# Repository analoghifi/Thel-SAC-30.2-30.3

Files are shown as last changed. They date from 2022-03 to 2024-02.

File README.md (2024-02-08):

# Thel SAC 30.2/30.3
Thel "**S**uper **A**ctive **C**rossover" (german: SA**W** 30.2/30.3) | 2-input ➔ 4-ouput | switchable: either 2-way-stereo or 3-way-mono | 24dB/Oct. Linkwitz-Riley  
realized as a 4th-order "state variable filter" according to:  
*>> Audio-Engineering-Society, Edition 1983 October 8-12, No. 2011 (B-2) by its inventor **Dennis A. Bohn**, Rane Corporation, Mountlake Terrace, Washington <<*  
➔ <a href="/docs/related/2099_AES_preprint_2011(B2)_1983.pdf">2099_AES_preprint_2011(B2)_1983.pdf</a>

maintaining a phase shift of 0° between the filter passes\* at any time at any frequency.  
*>>All in all, this results in perfect transmission in terms of time and level. The compromise is that the frequency-dependent phase rotation of this analogue filter is not shifted between the neighboring filter passes\*, but only between the input and output of the crossover.<<*  
  
\*(low-pass / band-pass / high-pass)   
<hr />

The original versions are equipped with balanced (symmetrical ) audio inputs  
but unbalanced (asymmetrical) audio outputs.
<hr />

In the <a href="/hardware">"hardware"</a> folder of this repository you can see the different versions of this module as they were built by THEL over the years and decades.  
This does NOT necessarily mean that the latest, newest version ("version 07.2017 until now") is also the "best" version.  
As you can see, in this case the sub-bass-boost feature and the extended supply voltage section is missing in the latest SAC 30.x  
and the very good PP 1% film/foil precision capacitors were switched to "normal" WIMA MKP 2.5% - 10% (or even MKS only).  
However, the latter in particular contradicts the goal of the 0° phase shift, because this requires that the determining filter capacitors and resistors have a tolerance of 1% or better (!).  
(In addition, the PP film/foil also sound better than the MKP types ➔ lower (and less frequency-dependent) dissipation factor "tan delta" etc...)  
On the other hand the latest, newest version ("version 07.2017 until now") introduces a much better input section (with 2 Op-Amps) in comparision to the previous model ("version 2011-2017")  
  
### So here is a comparison of this two versions and their specific pros and cons:  
#### Latest "<a href="/hardware/2)%20version%2007.2017%20until%20now">version 07.2017 until now</a>":  
:x: no "bass-boost" feature  
:x: using only "normal" capacitors in the filter section WIMA MKP 2.5% - 10% (or even worse: WIMA MKS)  
:x: no "Multi-Footprint" for the 8 filter capacitors (to optionally use different sizes and shapes of filter caps)  
:x: therefore no possibility to use the beloved tower style 1% precision KP film/foil caps in the filter section  
:x: no input caps in the power supply section  
:x: using of SOT-32 power transistors "only" in the power supply section (BD139/BD140 80V/1,5A/1,25W)  
:x: limited power supply voltage range of ±9V ... ±36V DC "only"  
:x: no possibility and space on the PCB to use optional (front panel mount) level potentiometers  
:x: no (RF-) bypass caps directly on the supply pins of the OP amps, although they are mandatory in every data sheet (for very good reasons)  
:heavy_check_mark: better audio input section with 2 OP-Amps (better symmetry / higher CMRR)   
:heavy_check_mark: using lower resistors in the filter section (less noise in theory)  
:heavy_check_mark: smaller dimensions (85 x 121mm)   
#### Previous "<a href="/hardware/3)%20version%202011-2017">version 2011-2017</a>":  
:heavy_check_mark: "bass-boost" feature  
:heavy_check_mark: using the high grade tower style 1% precision KP film/foil caps in the filter section  
:heavy_check_mark: "Multi-Footprint" for the 8 Filter capacitors to optionally use different sizes and shapes of filter caps  
:heavy_check_mark: 2 input caps (100µF) in the power supply section  
:heavy_check_mark: using of TO-220 power transistors in the power supply section (TIP132/TIP137 100V/8A/2,0W)  
:heavy_check_mark: extended power supply voltage range of ±9V ... ±60V DC  
:heavy_check_mark: preparation for using optional (front panel mount) level potentiometers directly on the PCB (in this case: TKD CP601 \[Conductive Plastic\])   
:x: no (RF-) bypass caps directly on the supply pins of the OP amps, although they are mandatory in every data sheet (for very good reasons)  
:x: using a simplified audio input section with 1 OP-Amp only (worse symmetry / lower CMRR)  
:x: using higher resistors in the filter section (more noise in theory)    
:x: larger dimensions (95 x 142mm)  
### my plans:  
* in the first step I will design a \"<a href="/hardware/1)%20my%20new%20version">new SAC30</a>\", which combines the advantages of the two versions mentioned above,  
it will still be in THT technology but 2 layer PCB, so that an average hobbyist can easily build it himself       
* the next step will be to create an all SMD version of this (eventually including 1% C0G ceramic filter caps), with some new features like symmetrical outputs, input/output ESD protection, ...)

<hr />  

## latest version as of 07.2017 until today:  
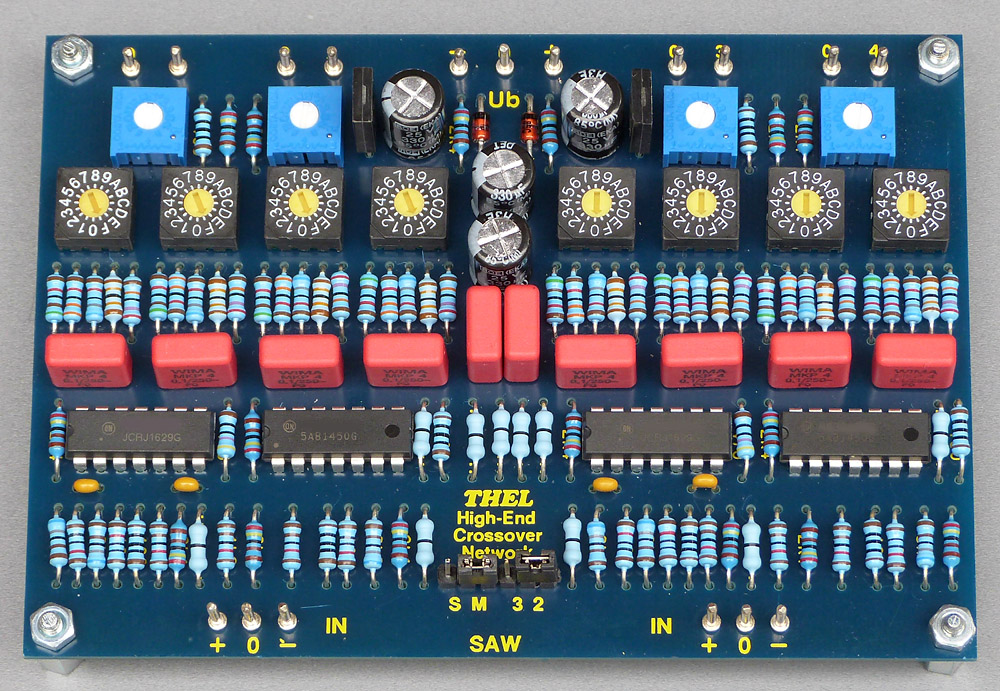
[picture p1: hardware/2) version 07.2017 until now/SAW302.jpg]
  
  
## better previous version (built 2011-2017):
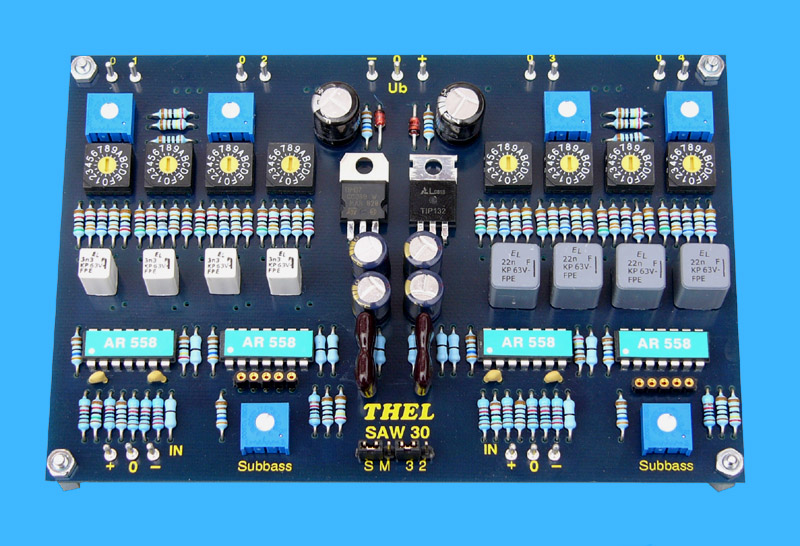
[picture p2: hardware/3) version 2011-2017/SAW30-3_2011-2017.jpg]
   
using optional (front panel mount) level potentiometers directly on the PCB (in this case: TKD CP601 [Conductive Plastic]):   
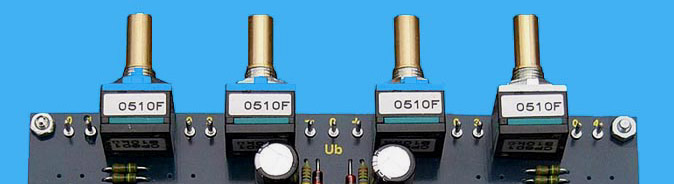
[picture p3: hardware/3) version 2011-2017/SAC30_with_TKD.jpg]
   

https://web.archive.org/web/20071014012620/http://www.thel-audioworld.de/module/saw/saw.htm  
old frequency-table: https://web.archive.org/web/20160324050324/http://thel-audioworld.de/module/saw/SAWTAB.GIF  
https://web.archive.org/web/20110927050632/http://www.thel-audioworld.de/module/saw/saw.htm  
https://web.archive.org/web/20160406211449/http://www.thel-audioworld.de/MODULE/SAW/saw.htm  
https://web.archive.org/web/20180819222254/http://www.thel-audioworld.de/module/SAW/saw.htm  

----

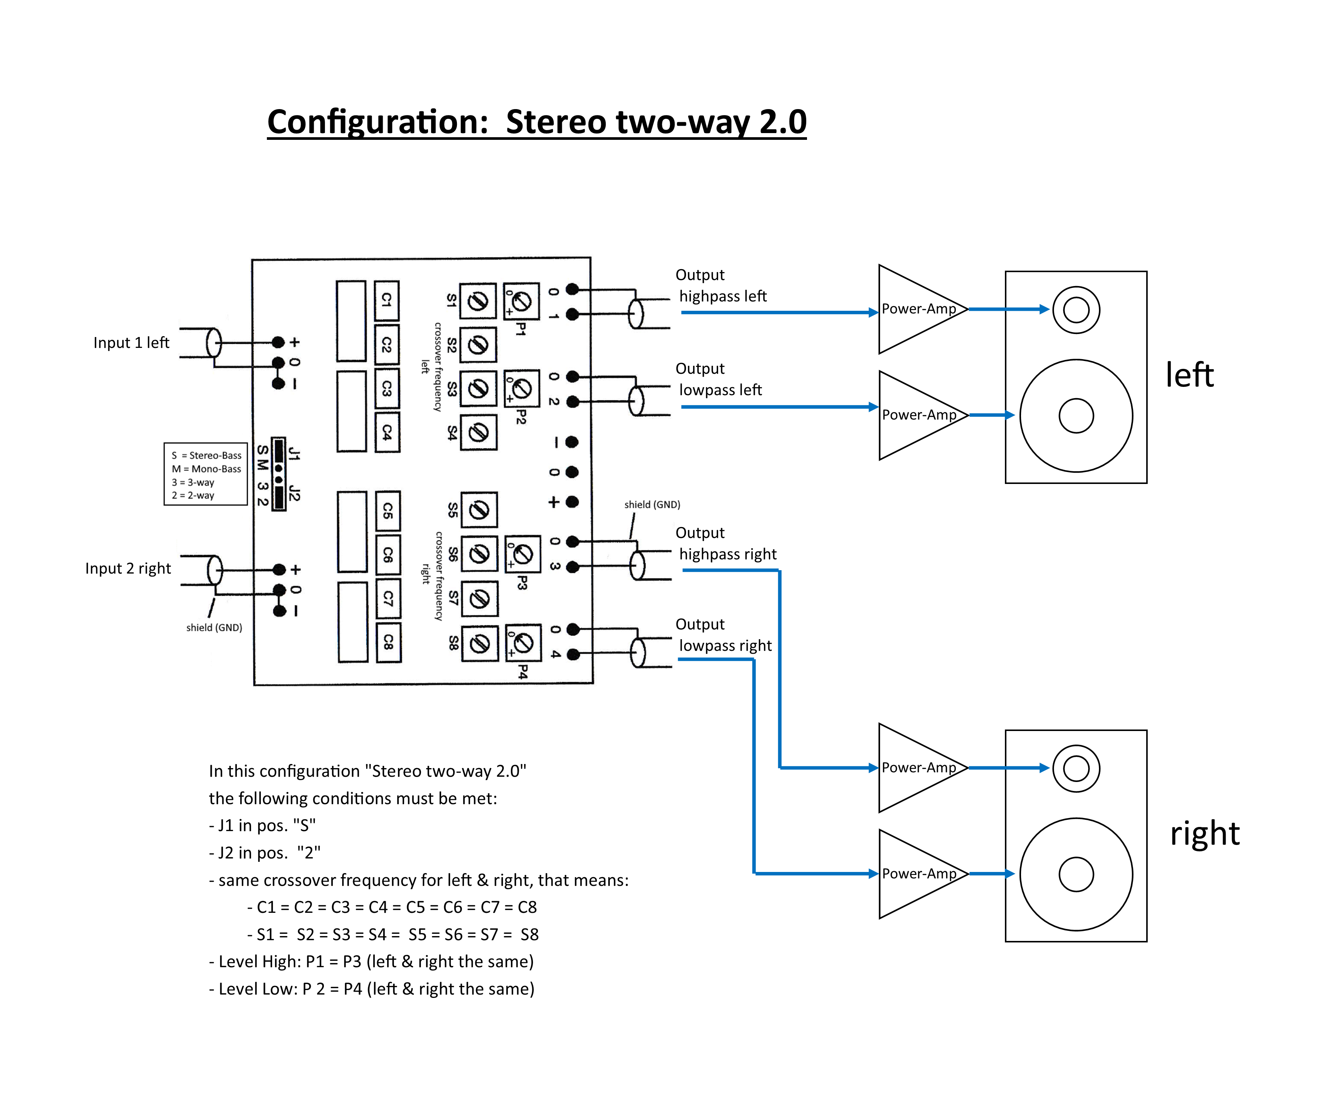
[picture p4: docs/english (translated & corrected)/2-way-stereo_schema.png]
  
  
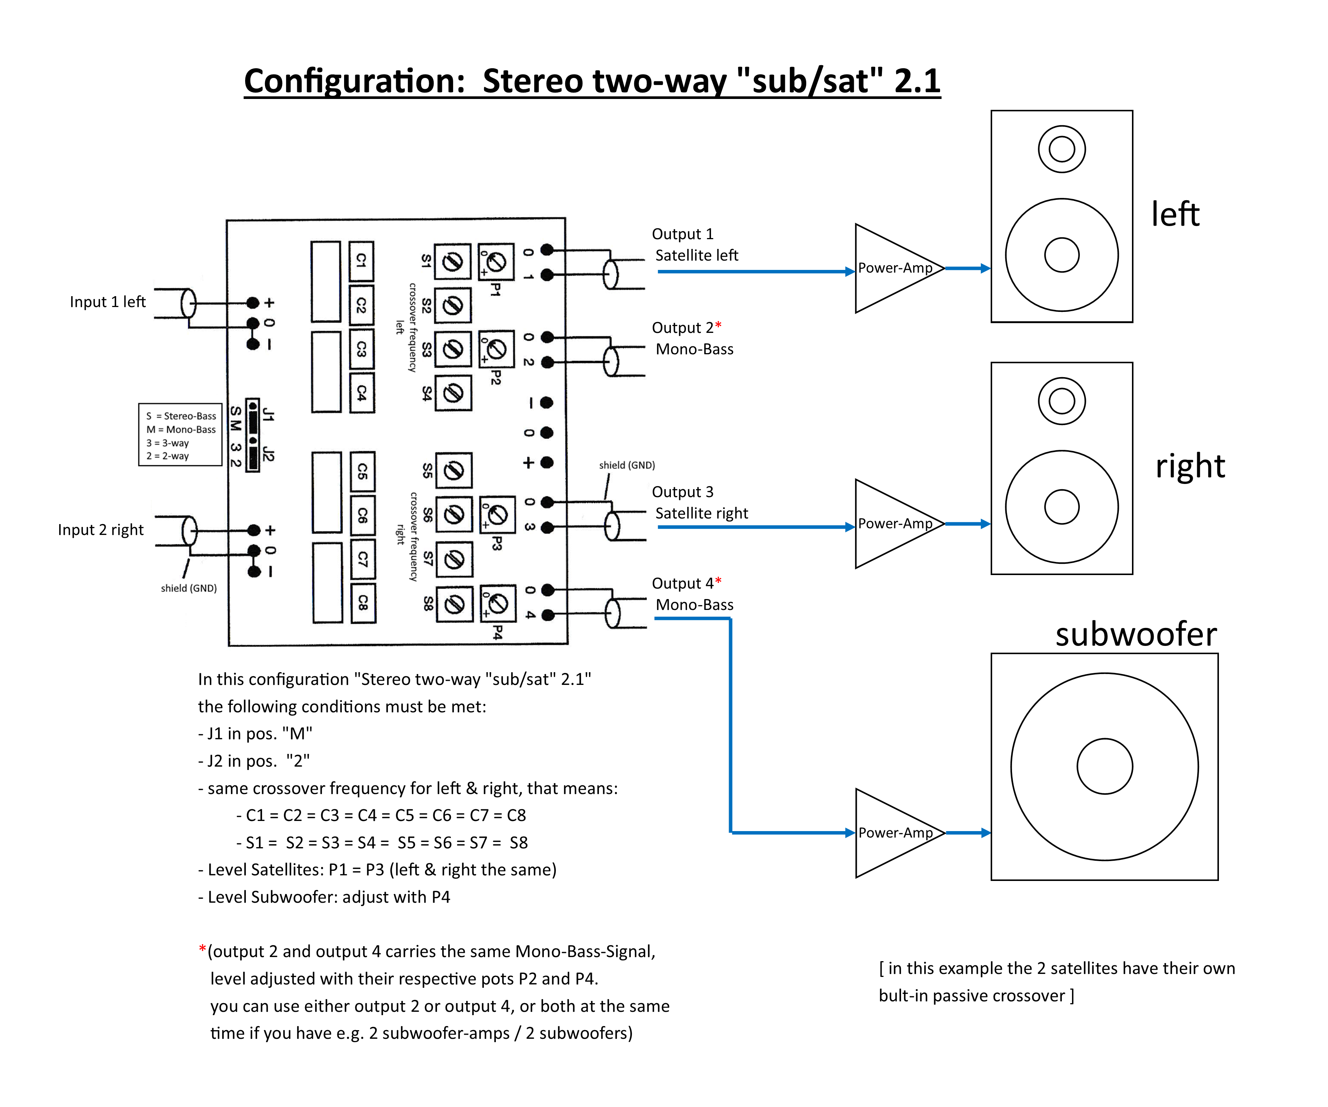
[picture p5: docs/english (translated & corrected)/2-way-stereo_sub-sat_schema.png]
  
  
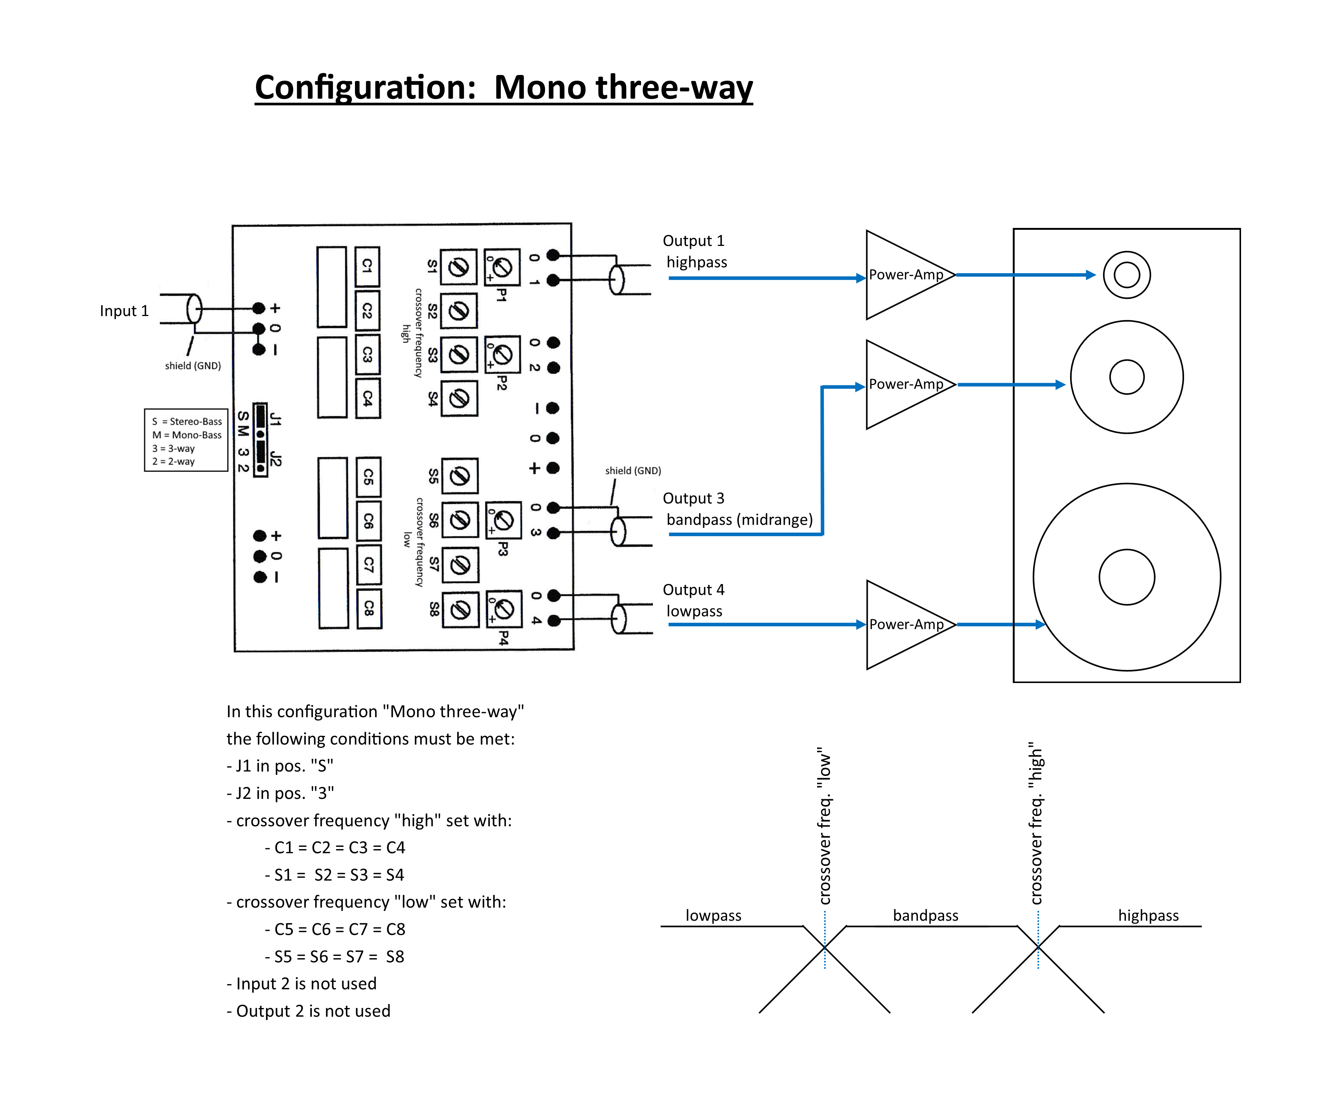
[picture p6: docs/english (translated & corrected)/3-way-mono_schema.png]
  

----

here's a link to a calculation table (spreadsheet)  
to choose the right capacitors and resistors for a certain crossover frequency and to get the desired adjustment range:  
https://docs.google.com/spreadsheets/d/1a5ryznVy3UrqgniDteTX_oCJn4powWA7M3F-0194jWU/edit?usp=sharing

----  
### Kicad projects in this repo:  
* [version 2011-2017](https://github.com/analoghifi/Thel-SAC-30.2-30.3/tree/main/hardware/3\)%20version%202011-2017/KiCad/original) | state: initial release v1.01 | like the original, 1-layer, THT
* [version 07.2017 until now](https://github.com/analoghifi/Thel-SAC-30.2-30.3/tree/main/hardware/2\)%20version%2007.2017%20until%20now/KiCad/original) | state: initial release v1.01 | like the original, 1-layer, THT
* [my new version THT](https://github.com/analoghifi/Thel-SAC-30.2-30.3/tree/main/hardware/1\)%20my%20new%20version/KiCad/1.1\)%20my%20THT%20version) | state: coming soon... | 2-layer, THT
* [my new version SMD](https://github.com/analoghifi/Thel-SAC-30.2-30.3/tree/main/hardware/1\)%20my%20new%20version/KiCad/1.2\)%20my%20SMT%20version) | state: coming soon... | 2-layer, SMD

----

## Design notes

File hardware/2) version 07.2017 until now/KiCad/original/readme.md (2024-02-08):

this is not the original Thel PCB but it's very like\* the original with the following exceptions:  
* more massive ground and power supply PCB tracks  
* using the 2mm gold-plated brass solder pins (the same ones used on the more expensive Thel modules)
* using a combined 5.0mm/7.5mm pin spacing footprint for all of the foil caps (C1 - C8, C13,C14) 
  
\*(same schematic / same board dimensions / same 1-layer\*\* layout THT / same THT components in the same places on the board)  
\*\*(strictly speaking, this KiCad PCB is a two-layer PCB with plated-through holes, but you can also (let) produce it as a classic 1-layer PCB with non-plated holes if you wish, since all the tracks are on the bottom side only)  
  
----  
  
### remarks:  
#### U1,U2,U3,U4:  
instead of [MC33079](https://github.com/analoghifi/Thel-SAC-30.2-30.3/blob/main/docs/components%20datasheets/MC33079_Motorola.pdf) you can use
2 pieces\*\* of the dual op amp [LME49720](https://github.com/analoghifi/Thel-SAC-30.2-30.3/blob/main/docs/components%20datasheets/LME49720.pdf) or [LM4562](https://github.com/analoghifi/Thel-SAC-30.2-30.3/blob/main/docs/components%20datasheets/LM4562.pdf) (both\* Texas Instruments),  
with slightly better technical data regarding noise and THD.  
  
\*(these two are 100% identical (even regarding their inner guts))  
  
\*\*(two pieces of dual op amps replace one of the quad op amp MC33079 - you have to use an adapter-PCB for it  
-> search for "dual-opamp to quad-op-amp adapter" on google -> there are different versions available.  
The adapter (target) footprint has to be 14-pin DIP with pins on a 0.1 inch pitch in rows spaced at 0.3 inch)
  
----  
  
these are KiCad 6.x projects  
see how to get the proper 3D-Models from here: https://github.com/analoghifi/KiCad-3D-Models  

use kicanvas.org to see this KiCad-Project in your browser:  
https://kicanvas.org/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

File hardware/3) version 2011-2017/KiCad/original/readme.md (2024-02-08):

this is not the original Thel PCB but it's very like\* the original with the following exceptions:  
* more massive ground and power supply PCB tracks  
* using the 2mm gold-plated brass solder pins (the same ones used on the more expensive Thel modules)
* make use of my \"universal capacitor footprint\" for the filter caps (C1 - C8) -> see here T.B.D.
* using a combined 5.0mm/7.5mm pin spacing footprint for the two bypass (foil) caps (C17, C18) 
  
\*(same schematic / same board dimensions / same 1-layer\*\* layout THT / same THT components in the same places on the board)  
\*\*(strictly speaking, this KiCad PCB is a two-layer PCB with plated-through holes, but you can also (let) produce it as a classic 1-layer PCB with non-plated holes if you wish, since all the tracks are on the bottom side only)  
  
----  
  
### remarks:  
#### U1,U2,U3,U4:  
instead of [MC33079](https://github.com/analoghifi/Thel-SAC-30.2-30.3/blob/main/docs/components%20datasheets/MC33079_Motorola.pdf) you can use
2 pieces\*\* of the dual op amp [LME49720](https://github.com/analoghifi/Thel-SAC-30.2-30.3/blob/main/docs/components%20datasheets/LME49720.pdf) or [LM4562](https://github.com/analoghifi/Thel-SAC-30.2-30.3/blob/main/docs/components%20datasheets/LM4562.pdf) (both\* Texas Instruments),  
with slightly better technical data regarding noise and THD.  
  
\*(these two are 100% identical (even regarding their inner guts))  
  
\*\*(two pieces of dual op amps replace one of the quad op amp MC33079 - you have to use an adapter-PCB for it  
-> search for "dual-opamp to quad-op-amp adapter" on google -> there are different versions available.  
The adapter (target) footprint has to be 14-pin DIP with pins on a 0.1 inch pitch in rows spaced at 0.3 inch)
    
----  
  
these are KiCad 6.x projects  
see how to get the proper 3D-Models from here: https://github.com/analoghifi/KiCad-3D-Models  
  
use kicanvas.org to see this KiCad-Project in your browser:  
https://kicanvas.org/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

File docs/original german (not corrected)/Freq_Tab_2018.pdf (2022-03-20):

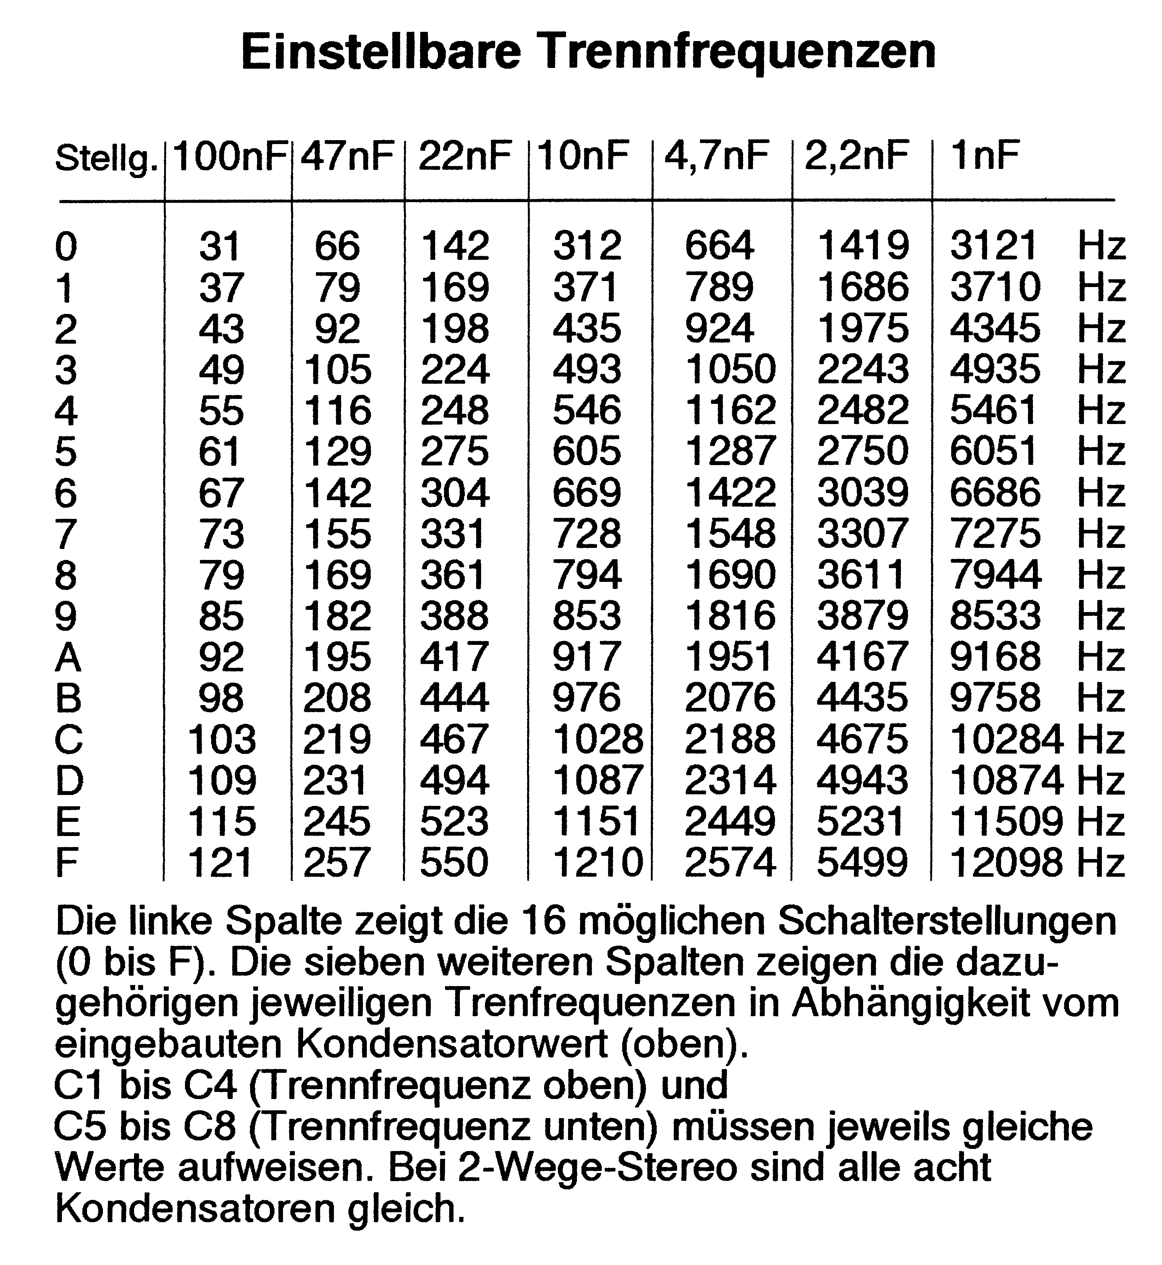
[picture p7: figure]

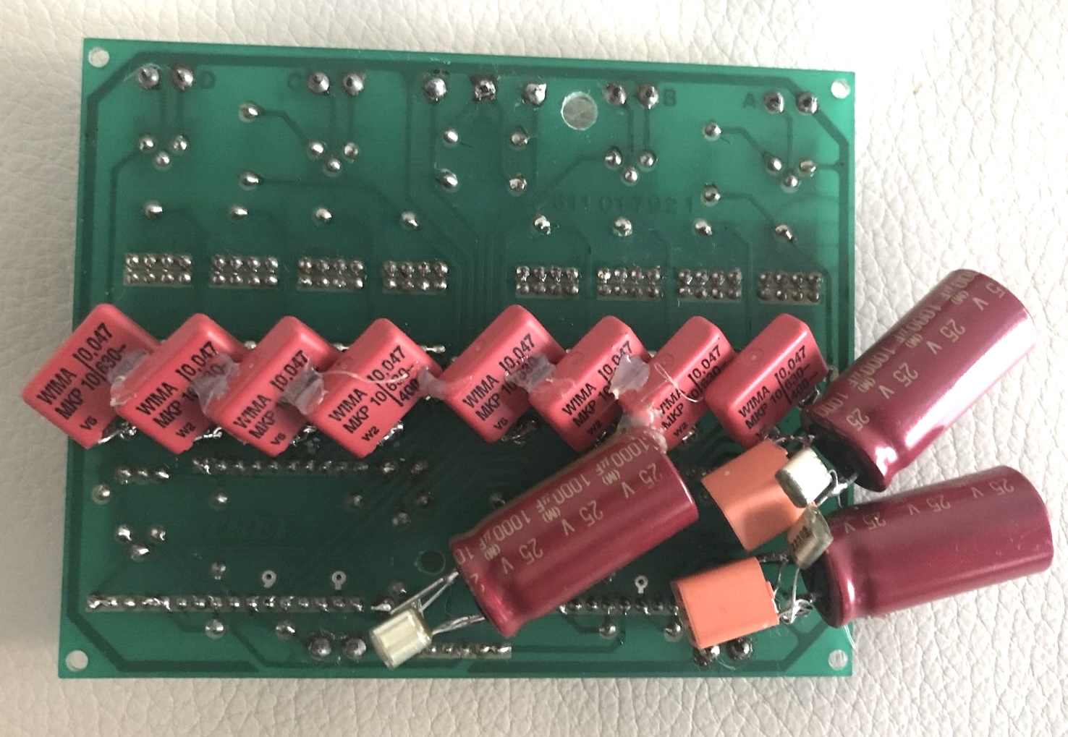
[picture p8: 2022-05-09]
hardware/6) version 1991-1994/SAW-30_modified_2.jpg

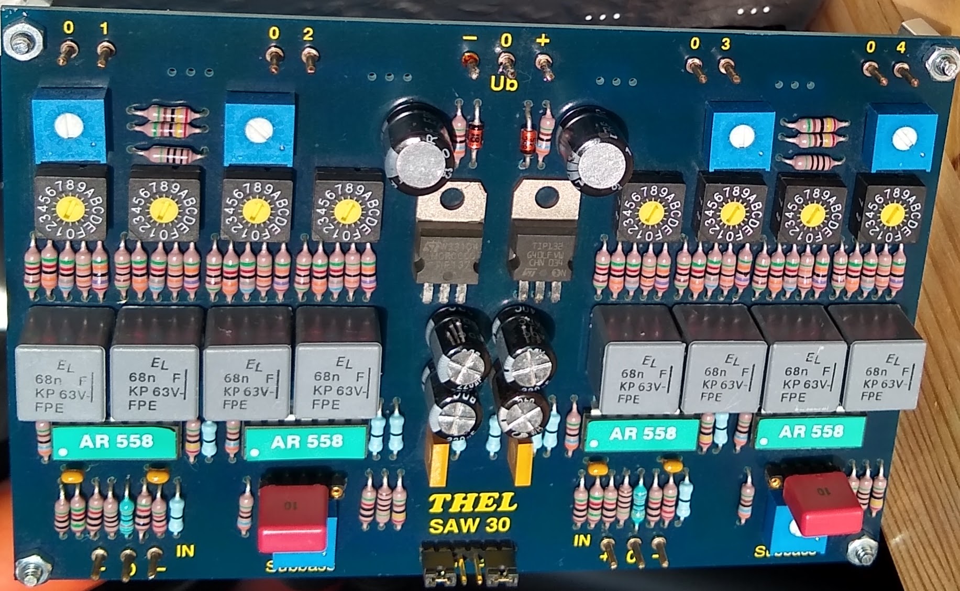
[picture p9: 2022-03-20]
hardware/3) version 2011-2017/SAW-30_2011_2017_top_2.jpg

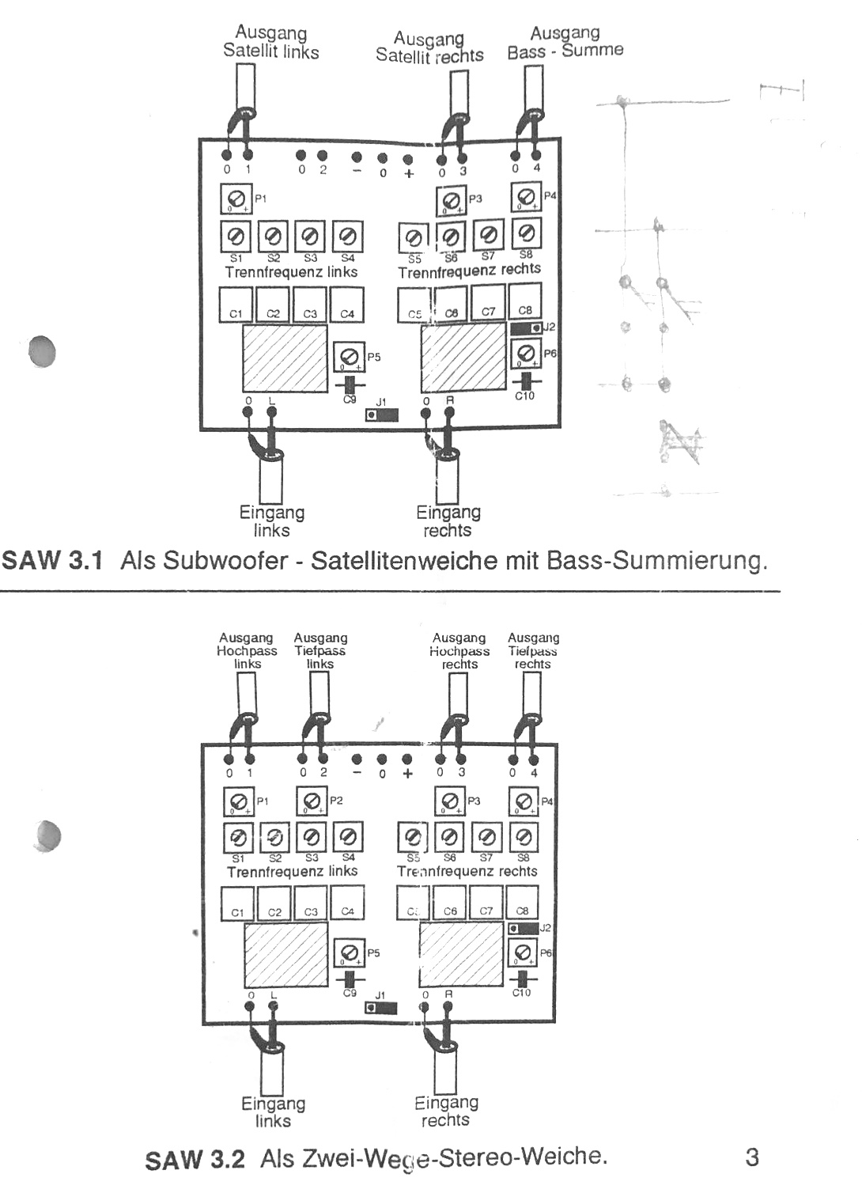
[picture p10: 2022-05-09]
hardware/6) version 1991-1994/SAW-30_4.jpg

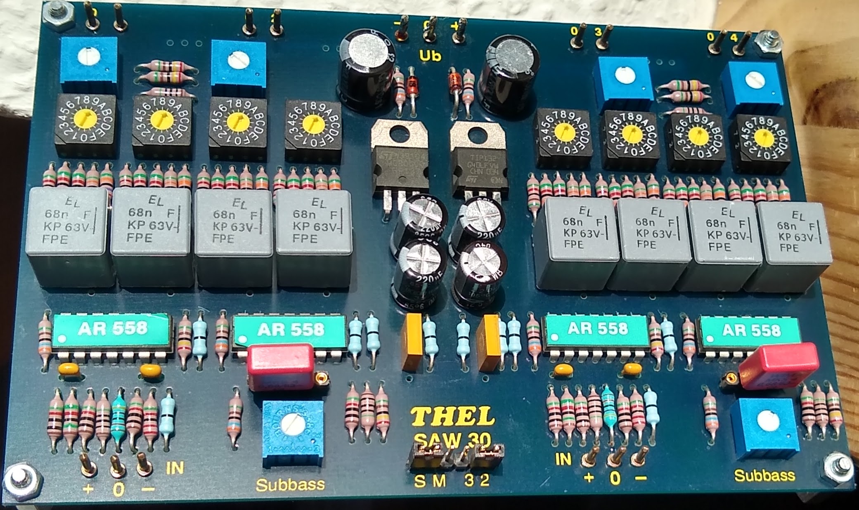
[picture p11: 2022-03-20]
hardware/3) version 2011-2017/SAW-30_2011_2017_top_1.jpg

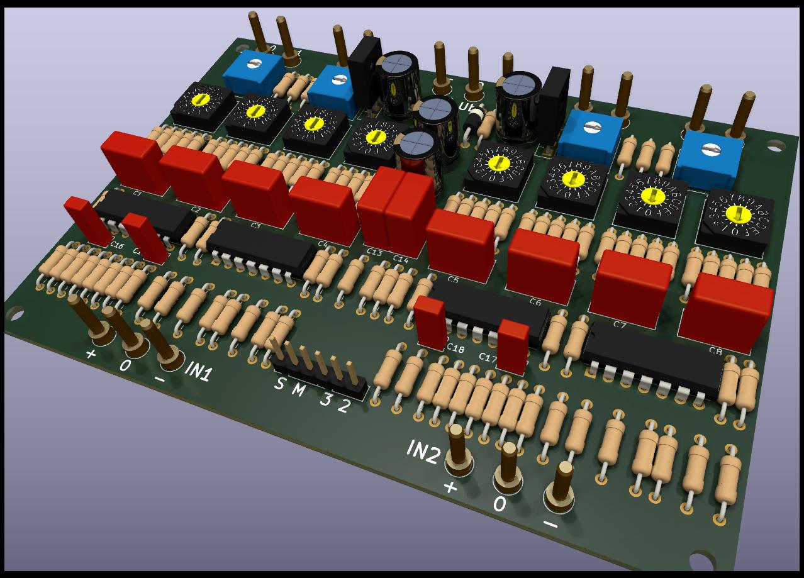
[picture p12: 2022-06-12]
hardware/2) version 07.2017 until now/KiCad/original/SAW30_original_1Layer_THT__3D.jpg

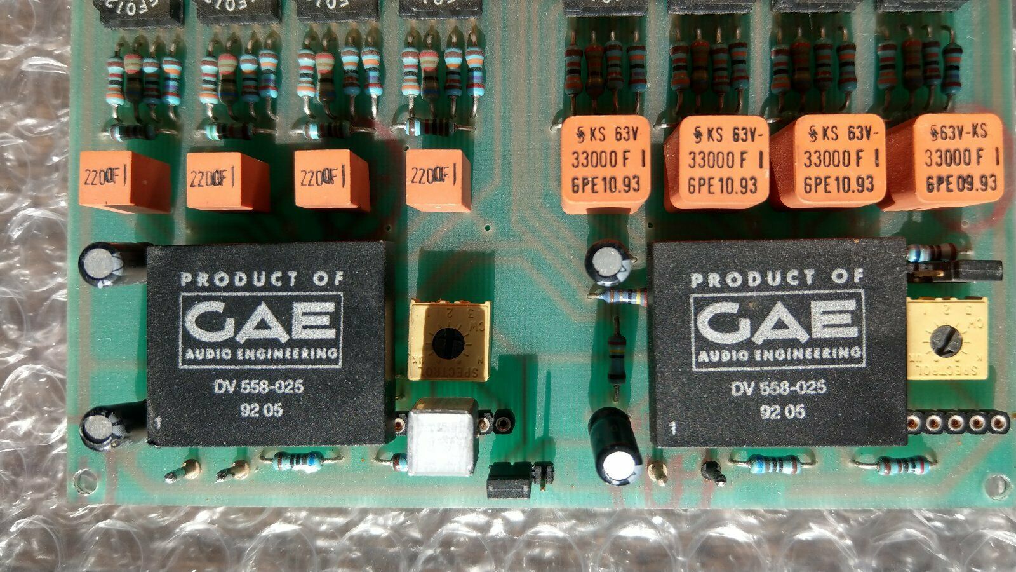
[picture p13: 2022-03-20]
hardware/6) version 1991-1994/Thel_SAW_30_1991-1994__3.jpg

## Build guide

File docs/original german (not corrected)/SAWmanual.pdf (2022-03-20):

# Aktivweiche SAW 30

Einstellbar als Zwei-Wege, Drei-Wege oder Subwoofer-Satelliten-Weiche.
Diese Betriebsarten sind mit ein unä derselben Platine möglich und werden mit den Jumpern J1 und J2 eingestellt, wie es weiter hinten beschrieben ist.
Die vier Ausgänge (0-1 bis 04) werden an die jeweils nachfolgenden Endstufeneingänge angeschlossen. Je nach Betriebsart sind die Ausgangsbelegungen verschieden.

Einstellung der Trennfrequenzen.
Mit den 16-stufigen Drehschaltern 51 bis 58 werden die Trennfrequenzen eingestellt. Wichtig: Die vier Schalter 51 bis S4 und S5 bis 58 müssen untereinander imrner die gleiche Stellung haben, damit die Phasengleichheit und Summe Eins gegeben ist. Wer davon abweichen möchte, darf die Schalter auch -unterschiedlich einstellen. Jedoch darf die Abweichung maximal 3 Stellungen betragen, darüberhinaus fängt die Weiche eventuell zu Schwingen är1, wodurch u nm ittelbar Lautsprecherchassis zerstört werden kön nen.
Die Drehschalterhaben einen Pfeil, der die Schalterstellung anzeigt, die Sie auch am linken Rand der Frequenztabelle wiederfinden, Bitte nicht im eingeschalteten Zustand die Schalter verdrehen.
Mit Hilfe der Tabelle auf der letzten Seite erkennen Sie, welche Frequenz zur jeweiligen Schalterstellung gehört. ln der obersten Reihe finden Sie die Werte der Filterkondensatoren mit denen lhre Platine bestückt ist. Cl bis C4 und C5 bis C8 müssen jeweils die gleichen Werte haben.

Pegeleinstellung.
Mit den Potis pf Ois P4 lassen sich die einzelnen Ausgangspegel der Kanäle abgleichen. Von links nach rechts gedreht ergibt sich eine Ausgangsspannung zwischen Null und dem 3-fachen Eingangssignal. Ali-e Pegel sind ab Werk genau auf Verstärkung 1 eingestellt. Dadurch können Sie siclier §ein, daß der linke und rechte Kanal in der Balance ausgeglichen sind. Beim Pegelabgleich sollte daher nach Möglichkeit ein Kanal unverändert bleiben. Beim Dreiweg z.B. der Mittenkanal, beim Zweiweg z.B, där Hochtonkanal, (Referenzkanäle). Sind alle Pegel mit dern Werksabgleich im ganzen zu hoch oder zu niedrig, muß natürlich jeder Einsteller verändert werden. Alle Pegel sollten aber nicht weiter aufgedreht werden, wie es zur Vollaussteuerung der Endstufen notwendig ist. Dadurch wird der größtmögliche Rauschabstand der gesamten Anlage erreicht. - Je nach Betriebsart ist nicht jedes Poti in Betrieb.

Ei nstell bare Trennfreq uenzen

Stellg | 4,7nF 2,ZnF 1nF <C

Technische Daten
Betriebsspannung *5V bis r36V optimal r12V bis *20V Stromaufnahme max.40mA
Flauschabstand >100 dB
Lastwiderstand min. 600 O
Eingangswiderstand 10 k§)
Klirrfaktor ges. <0,0024/o Anstiegszeit (HP) 1 Fs fo HochPass +0dB=300kHz fu Tiefpass 0 Hz (DC)

Gyratorähnliche Schaltu ng
Seit 42006 wird die neue Version der Weiche mit Gyratorschaltung in der Spannungsversorgung ausgeliefert. Diese Scfialtung bewirkt eine sehr hohe Glättun gswirkung der Versorg u n gsspan n u n g, so dass sogar eine schlecht gesiebte Spannung verwendet werden kann.
Außerdem wird intern auf t17V begrenzt, so dass eine wesentlich höhere Spannung angelegt werden kann, maximalca. t35 Volt. Daher kann die Weiche bei Bedarf auch aus vorhandenen Netzteilen mit höheren Betriebsspannungen versorgt werden, ohne dass diese Spannung herabgeseEt werden muss.

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
4,14
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
1028
1087
1151

664
789
924
1050
1162
1287
1422
1 548
1 690
't816
1 951
2A76
2188
2314
24,r',9
2574

1419
1686
1975
2243
2482
2750
3039
3307
361 1
3879
4167
4tr.35
4675
4943
5231
121 | 5499

3121 Hz
3710 Hz
43r'5 Hz
4935 Hz
5461 Hz
6051 Hz
6686 Hz
7275 Hz
7944 Hz
8533 Hz
9168 Hz
9758 Hz
10284 Hz
10874 Hz
'l 1509 Hz
12A98Hz
Die linke Spalte zeigt die 16 möglichen Schalterstellungen (0 bis F). Die sieben weiteren Spalten zeigen die dazugehörigen jeweiligen Trenfrequenzen in Abhängigkeit vom eingebauten Kondensatonrvert (oben).
Cl bis C4 (Trennfrequenz oben) und
C5 bis C8 (Trennfrequenz unten) müssen jeweils gleiche Werte aufueisen. Bei2-Wege-Stereo sind alle acht Kondensatoren gleich.

EingangsbeSChaltung. Asymmetrischer / symmetrischer Betrieb.

Die Eingänge der SAW 30 lassen sich sowohl symmetrisch als auch asymmetrisctt betreiben. Dazu muß immer der unbenuäeEingangs-pin mit Masse (0) verbunden-werden, wie Sie auf den Abbildungen sehen können.
+0-
a .F{| Asymmetrischer, I I nichtinrrertiercn&r I I Eingang.

## rl'.'l

.fl, standard-Anschtuß

Die Eingangspins sind so
angeordnet, daß die nötige Brücke einfach dadurch
hergestellt werden kann,
indem man die Schirmung
des Kabels zwiscten zwei
Pins hät, und diese dann
miteinander verlötet.

+0-
Asymmetrischer,
invertierender
Eingang.

Steuerung über Endstufe

Manchmal ist keine auftrennbare Vorstule vorhanden und man möchte die Weiche lediglicfr lür einen zusätzlichen Subwooler einsetzen. Dann kann man, wie abgebildet, den Lautsprecherausgang einer Endstufe benutzen und von dort über einen Spannungsteiler auf den Eingang der Weiche gehen.

Achtung. Die NF-Eingangsspannung darf nicht den Wert der internen Betriebsspannung der Weiche übersctreiten. max t20V

10k
Endstufe

Symmetrischer,
Eingang.
Die beiden signalführenden lnnenleiter werden
ä]l ,+'916 "-' angeschlossen; die Schirmung des Kabels an ,,0'.

### Symmetrischer Betrieb

Wie die Eingänge symmetrisch betrieben werden, zeigt das nebenstehende Bild. Obwohl die-Auägän!;e nur asymmetrisch vorhanderi'sind, so kann man durch den Betrieb einer Döppelweiche aucfi einen symmetischen fusgalg erhalten. Dazu muß jeder Hoc*i-'und Tielpass pro Kanal

-zweimal und völlig identisch vorhanden seiÄ. Weiter unten wird beschrieben, wie man aus einem asymmetrischen ein symmetiscfres Signal macht, oder wie man eine vollsymme.trische Anlage aufbaut. Actrten Sie immer auf die ricfrtigen Verbindungen der Eingänge.

0a 04
Hooh- Tiefpass pass
+0-
+0- | + 0- | +0- | +0-
Symmetrischer
Ausgang

Symmetrischer
Ausgang

Vollsymffi€tri,
2-Wege Mono

aa
0l
Hocfipa§s
+0- ft{

## ol o2

Tiefpass

oö
03

## tao4

Hoc*r- Tiefpass pa§s

# +0- IH llrl sch .f

sAw 30.2

Asymmetrischer
Eingang

Symmetrischer
Eingang

### symmetrierend

2-Wege Mono

Allgemeines.
Die Aktivweiche ist DO-gekoppelt. Durch ungünstige Einflüsse, z,B, DO-Anteil einer Signalquelle und gleichzeitig angehobenem Basspegel, kann es sein, daß DC-Sctrutzschaltungen von Endstufen änsprechen, oder sonstige störende Auswirkungen auftreten. ln solchen Fällen genügt das Anbringen eines Kondensators (natürlich hochwertig) in den Endstufeneingang. (ln der Flegel mindestens 2,2ytF). Sollte dort schon einer vorhanden sein, dürfte es keine Probleme geben,
ln den Ausgängen der Weiche haben wir bewußt auf zusätzliche Halbleiter als Putferstufen vezichtet, Bei kurzen Verbindungen zu den Endstufen ist es nicht nötig, daß nach den Potis noch eine weitere Verstärkerstufe zweck§ niederohmiger Kabeltreibung eingesetzt wird. Dies könnte aber bei sehr langen Kabeln (>10m) erforderlich sein. Dulch einen kleinen Trick kann man aber auch hier auf die zusätzlichen
Pufferstufen verzichten: Drehen Sie alle Pegel-Potis ganz auf. Das Kabel wird nun durch die niederohmigen Treiberstufen der Analogrechner direkt und mit hohem Pege! getrieben, Zur Pegeleinstellung können jeEt Potis direkt an den Endstufeneingängen angebracht werden. Diese Version verursacht die geringstmöglichen Klangverfälschungen durch lange NF-Kabel.

Ausgang Ausgang
Hochpass links Tiefpass links

Ausgang Ausgang
Hochpass rechts Tiefpass rec,hts

### Aktivweiche SAW 3O.2

### Zwei-Wege-Weiche in Stereoausführung

Abschirmung

Jumperstellung.
Die beiden Jumper müssen gemäß der Skizze gesteckt sein. J1 auf ,,S" und J2 aul ,,2".
AnschluB der Ein- und Ausgänge.
Die ,,Rechts- Links-Ausgänge" eines Vorverstärkers müssen mit den Eingängen der Weiche
gemäß Zeichnung verbunden werden. Die Ausgänge der Weiche führen zu den Eingängen der Endstufen.
Pegelabgleich.
P1 bis P4 dienen zum Pegelabgleich der einzelnen Chassis.

Abschirmung

+ 03 04
E]" E

### @@@@ s5 s6 s7 ss

Trennfrequenz rechts

# EtqEE

+o- | J1 Jz | +o-
@@@@ s1 s2 s3 s4 | @@@@ s5 s6 s7 s8
Trennfrequenz links | Trennfrequenz rectts

c5 ll c6 ll c7 ll c8

+0- | J1 J2 | +0-

Ausgang
Satellit links

Ausgang
Monobass

Ausgang Ausgang

### Satellit rechtrs Monobass Aktivweiche SAW 30.2 S u bwoofer-Satel I itenweiche

Ausgang Monobass
Es kann wahlweise Ausgang 2oder Ausgang 4 oder beide gleichzeitig venrendet werden.
ln jedem Fall liefert jeder Ausgang das Bass-Summensignal beider Eingänge, wenn der Jumper auf ,,M" gesteckt wird.

Eingang
rechts

Zur Beachtung: Um die empfindlichen NF-Eingänge vor statischen Überspannungen durchPotentialausgleichströme iu scfrützen,

'sollte
vor dem Stecken oder Ziehen aller angeschlossen NF-Stecker die Betriebsspannung der Weiche immer ausgeschalttet sein. Auch dart die NF-Eingangsspannung nicht den Weft der Betriebsspannung der Weiche erreichen.

cr ll cz ll ca ll c4

### Aktivweiche SAW 30.3

### als Drei-Wege-Weiche in Monoausführung

Jumperstellung.
Die beiden Jumper müssen gemäß obiger Skizze gesteckt sein. J1 auf ,,S" und J2 auf ,,3".

Anschluß der Ein- und Ausgänge.
Für den Stereobetrieb sind zwei Aktivweichen, wie oben gezeigt, nötig. Die Signal-Ausgänge .eines Vorverstärkers werden ieweils mit den Eingängen der beiden Weichen verbunden. Die Ausgänge der Weichen werden mit den Eingängen der einzelnen Endstufen für die Dreiwege-Box verbunden.

Pegelabgleich. Pl, Pg und P4 dienen zum Pegelabgleich der

einzelnen Chassis.

sl st s3 s4 | s§ s6 s7 s8
Trennfrequenz oben | Trennfrequenz unten
TP | BP | HP

Eingang

Ausgang
Hochpass

Ausgang
Bandpass

Achten Sie auf die
Jumperstellungen der
einzelnen Platinen.
Lassen Sie die vier
Potis der Eingangsplatine für die Pegel
bitte auf Verstärkung
1 stehen.

Mit den acht Potis an
den Ausgängen, die
zu den Endstufen
führen, wird der
Pegelabgleich
vorgenommen.

Ausgang Ausgang Ausgang
Bandpass Tielpass Hochpass
unlen

Ausgang
Bandpass

Ausgang
Bandpass

Ausgang
Tbrpass

3 x SAW 30.3

### als Vier-Wege-

Weiche in Stereoausführung

BP unten BP oben

Trennlrequenz
unten

Treflnlrcquerz
oben

Trennfrequenz
mitte

@@@@ sl s2 s3 s4 @@@@ s5 s6 s7 s8

Trennlrequenzoben Trsrnlrequenz uotsr

# TEEIUIE tqEEE

+0- | Jl Jz +o-
01 | 02 [ l', @*

@@@@ sl s2 s3 s4

Trennlrequenz oben

# tiltqElE

@@@@ s5 s8 s7 s8

Trennfrequenz unten

## tEEEtse-I

+o- | JI Jz +o-
@@@@ s1 s2 s3 s4 | @@@@ s5 s6 s7 s8

Trenrfrequenz mitte links Trennfrequenz mine rechts

# EE@E E@EE

la .. . a a aa aa 0'f | 02 | 0 + 0s | 04
0 + 03 | 04
01 | 02 | 0 +

## fä1", E*

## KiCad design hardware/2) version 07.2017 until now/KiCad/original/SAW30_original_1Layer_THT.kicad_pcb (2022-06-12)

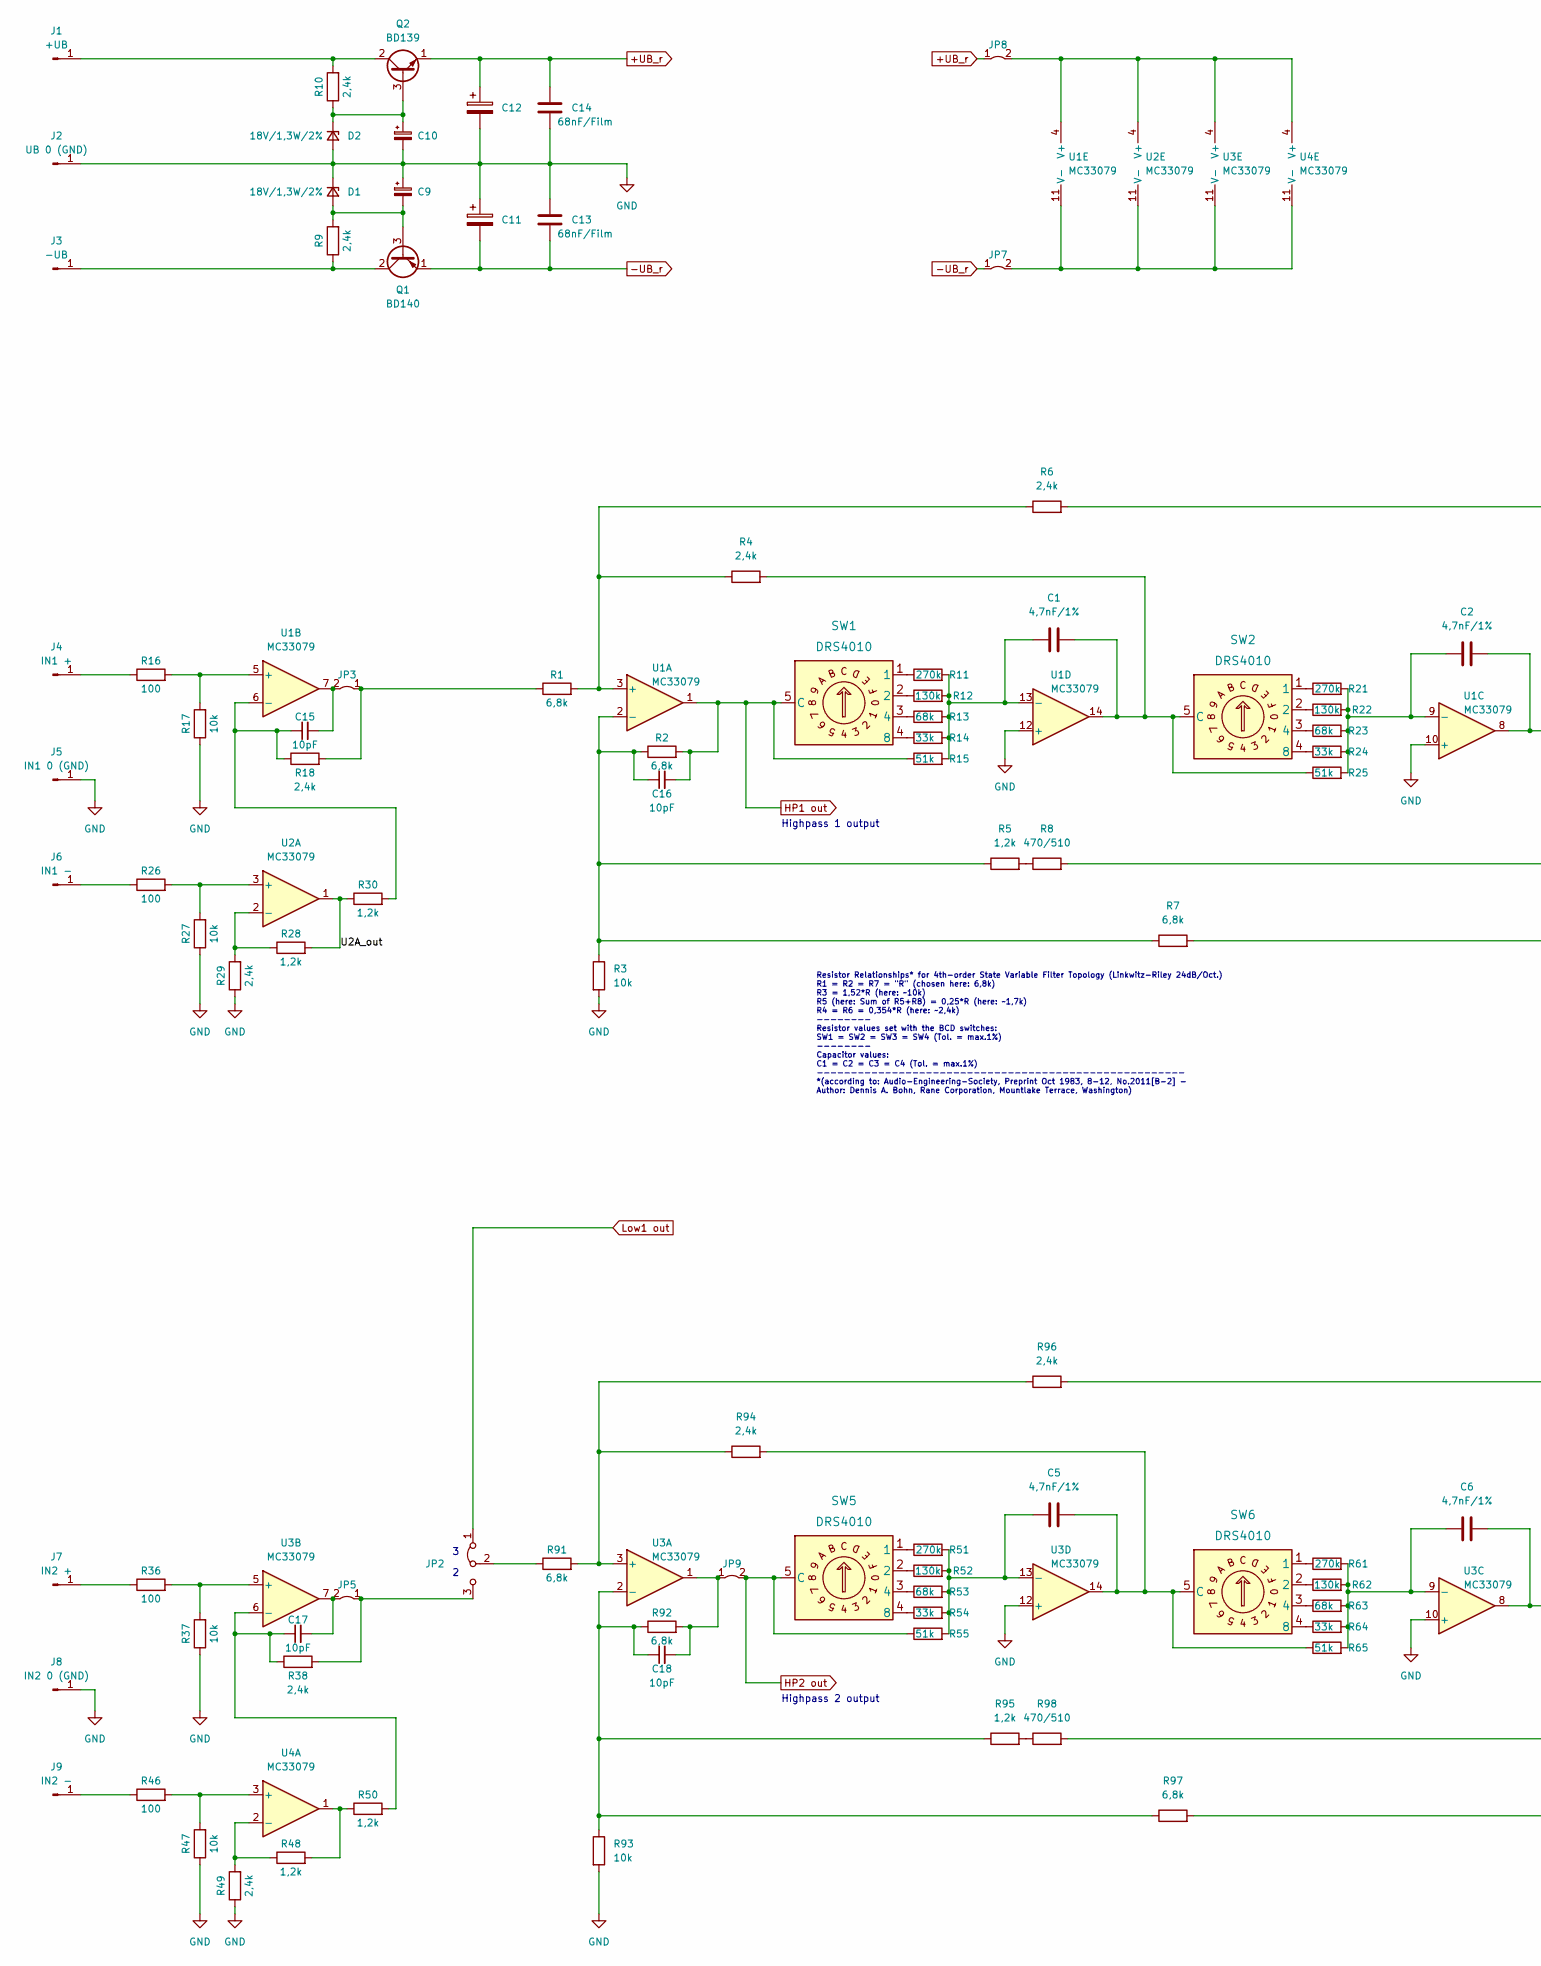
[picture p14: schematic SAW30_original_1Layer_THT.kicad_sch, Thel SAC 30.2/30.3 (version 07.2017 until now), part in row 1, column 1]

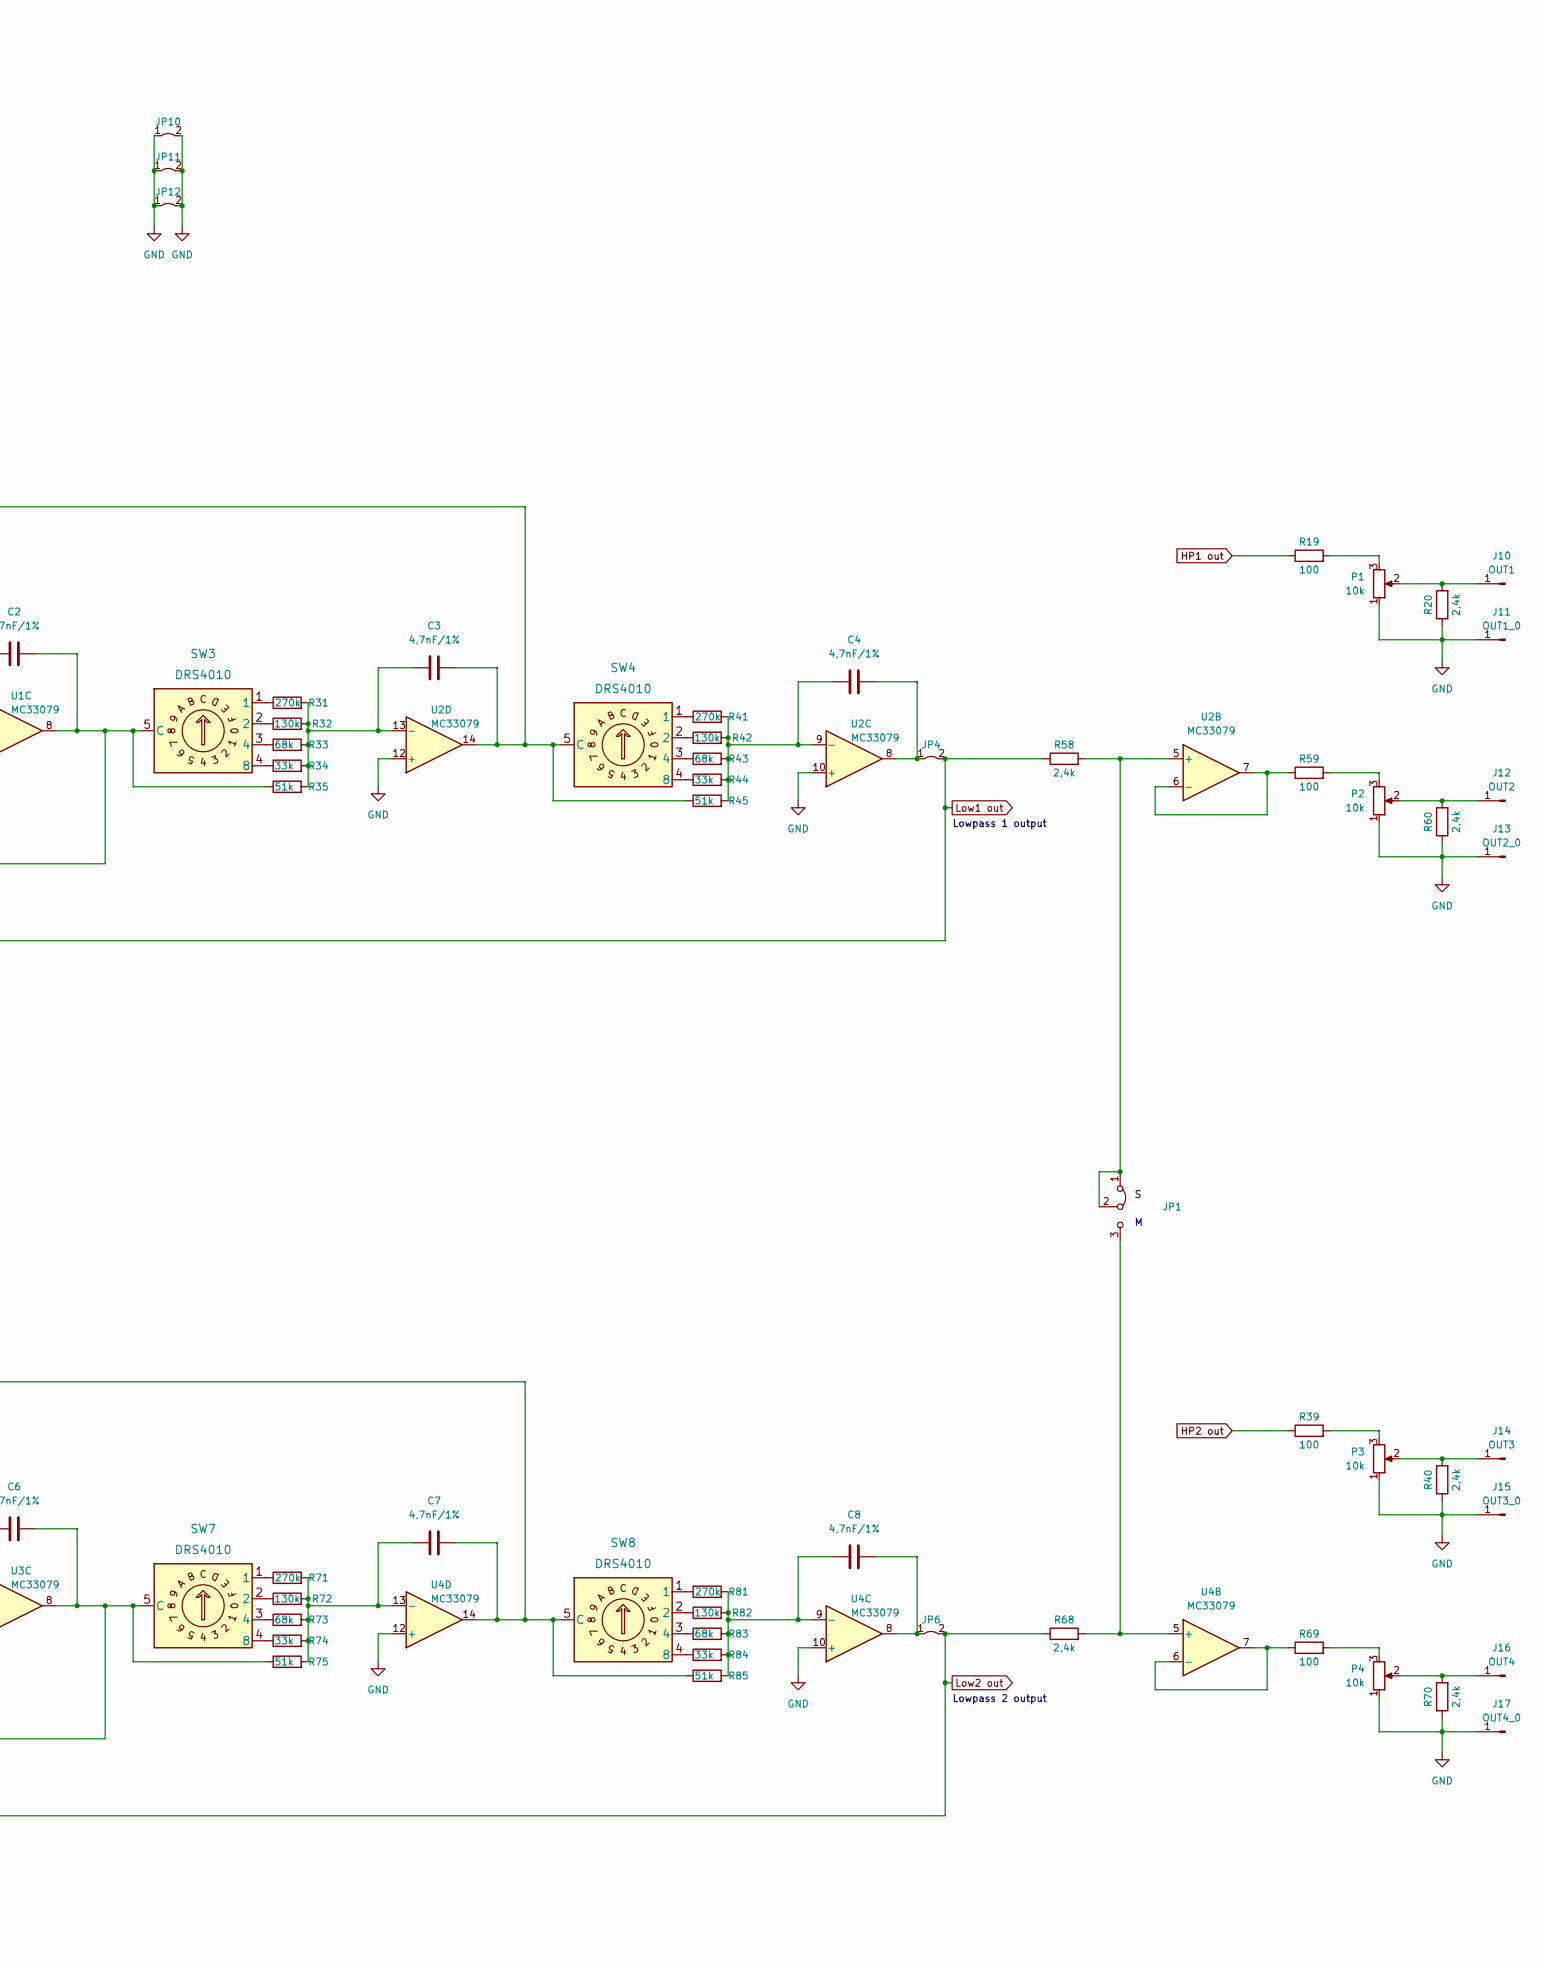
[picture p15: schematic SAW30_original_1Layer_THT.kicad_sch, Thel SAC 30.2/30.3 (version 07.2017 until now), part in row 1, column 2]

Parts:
C1, C2, C3, C4, C5, C6, C7, C8: 4,7nF/1%; C_Rect_L10.0mm_W5.0mm_P5.00mm_P7.50mm
C9, C10, C11, C12: (no value)
C13, C14: 68nF/Film; C_Rect_L10.0mm_W5.0mm_P5.00mm_P7.50mm
C15, C16, C17, C18: 10pF; C_Rect_L4.0mm_W2.5mm_P2.50mm
D1, D2: 18V/1,3W/2%; D_DO-41_SOD81_P10.16mm_Horizontal_minSilk
J1: +UB; Loet_Pin_D1.5mm_L14.0mm
J2: UB 0 (GND); Loet_Pin_D1.5mm_L14.0mm
J3: -UB; Loet_Pin_D1.5mm_L14.0mm
J4: IN1 +; Loet_Pin_D1.5mm_L14.0mm
J5: IN1 0 (GND); Loet_Pin_D1.5mm_L14.0mm
J6: IN1 -; Loet_Pin_D1.5mm_L14.0mm
J7: IN2 +; Loet_Pin_D1.5mm_L14.0mm
J8: IN2 0 (GND); Loet_Pin_D1.5mm_L14.0mm
J9: IN2 -; Loet_Pin_D1.5mm_L14.0mm
J10: OUT1; Loet_Pin_D1.5mm_L14.0mm
J11: OUT1_0; Loet_Pin_D1.5mm_L14.0mm
J12: OUT2; Loet_Pin_D1.5mm_L14.0mm
J13: OUT2_0; Loet_Pin_D1.5mm_L14.0mm
J14: OUT3; Loet_Pin_D1.5mm_L14.0mm
J15: OUT3_0; Loet_Pin_D1.5mm_L14.0mm
J16: OUT4; Loet_Pin_D1.5mm_L14.0mm
J17: OUT4_0; Loet_Pin_D1.5mm_L14.0mm
JP1, JP2: Jumper_3_Bridged12; PinHeader_1x03_P2.54mm_Vertical
JP3, JP4, JP5, JP6, JP7, JP8, JP9, JP10, JP11, JP12: Jumper_2_Bridged; Drahtbruecke_10.16mm
P1, P2, P3, P4: 10k; Potentiometer_Bourns_3386P_Vertical
Q1: BD140; TO-126-3_Vertical
Q2: BD139; TO-126-3_Vertical
R1, R2, R7, R91, R92, R97: 6,8k; R_Axial_DIN0207_L6.3mm_D2.5mm_P10.16mm_Horizontal_minSilk
R3, R17, R27, R37, R47, R93: 10k; R_Axial_DIN0207_L6.3mm_D2.5mm_P10.16mm_Horizontal_minSilk
R4, R6, R9, R10, R18, R20, R29, R38, R40, R49, R58, R60, R68, R70, R94, R96: 2,4k; R_Axial_DIN0207_L6.3mm_D2.5mm_P10.16mm_Horizontal_minSilk
R5, R28, R30, R48, R50, R95: 1,2k; R_Axial_DIN0207_L6.3mm_D2.5mm_P10.16mm_Horizontal_minSilk
R8, R98: 470/510; R_Axial_DIN0207_L6.3mm_D2.5mm_P10.16mm_Horizontal_minSilk
R11, R21, R31, R41, R51, R61, R71, R81: 270k; R_Axial_DIN0207_L6.3mm_D2.5mm_P10.16mm_Horizontal_minSilk
R12, R22, R32, R42, R52, R62, R72, R82: 130k; R_Axial_DIN0207_L6.3mm_D2.5mm_P10.16mm_Horizontal_minSilk
R13, R23, R33, R43, R53, R63, R73, R83: 68k; R_Axial_DIN0207_L6.3mm_D2.5mm_P10.16mm_Horizontal_minSilk
R14, R24, R34, R44, R54, R64, R74, R84: 33k; R_Axial_DIN0207_L6.3mm_D2.5mm_P10.16mm_Horizontal_minSilk
R15, R25, R35, R45, R55, R65, R75, R85: 51k; R_Axial_DIN0207_L6.3mm_D2.5mm_P10.16mm_Horizontal_minSilk
R16, R19, R26, R36, R39, R46, R59, R69: 100; R_Axial_DIN0207_L6.3mm_D2.5mm_P10.16mm_Horizontal_minSilk
SW1, SW2, SW3, SW4, SW5, SW6, SW7, SW8: DRS4010; DRS_3016_4010
U1, U2, U3, U4: MC33079; DIP-14_W7.62mm

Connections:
+UB_r: C12.1, C14.1, JP8.1 (A), Q2.1 (E)
-UB_r: C11.2, C13.2, JP7.1 (A), Q1.1 (E)
/U2A_out: R28.2, R30.1, U2.1
GND: C9.1, C10.2, C11.1, C12.2, C13.1, C14.2, D1.1 (K), D2.2 (A), J2.1, J5.1, J8.1, J11.1, J13.1, J15.1, J17.1, JP10.1 (A), JP10.2 (B), JP11.1 (A), JP11.2 (B), JP12.1 (A), JP12.2 (B), P1.1, P2.1, P3.1, P4.1, R3.2, R17.1, R20.1, R27.1, R29.1, R37.1, R40.1, R47.1, R49.1, R60.1, R70.1, R93.2, U1.10 (+), U1.12 (+), U2.10 (+), U2.12 (+), U3.10 (+), U3.12 (+), U4.10 (+), U4.12 (+)
HP1 out: C16.2, R2.2, R15.1, R19.1, SW1.5 (C), U1.1
HP2 out: JP9.2 (B), R39.1, R55.1, SW5.5 (C)
Low1 out: JP2.1 (A), JP4.2 (B), R7.2, R58.1
Low2 out: JP6.2 (B), R68.1, R97.2
unnamed: C1.1, R11.2, R12.2, R13.2, R14.2, R15.2, U1.13 (-)
unnamed: C1.2, R4.2, R25.1, SW2.5 (C), U1.14
unnamed: C2.1, R21.2, R22.2, R23.2, R24.2, R25.2, U1.9 (-)
unnamed: C2.2, R8.2, R35.1, SW3.5 (C), U1.8
unnamed: C3.1, R31.2, R32.2, R33.2, R34.2, R35.2, U2.13 (-)
unnamed: C3.2, R6.2, R45.1, SW4.5 (C), U2.14
unnamed: C4.1, R41.2, R42.2, R43.2, R44.2, R45.2, U2.9 (-)
unnamed: C4.2, JP4.1 (A), U2.8
unnamed: C5.1, R51.2, R52.2, R53.2, R54.2, R55.2, U3.13 (-)
unnamed: C5.2, R65.1, R94.2, SW6.5 (C), U3.14
unnamed: C6.1, R61.2, R62.2, R63.2, R64.2, R65.2, U3.9 (-)
unnamed: C6.2, R75.1, R98.2, SW7.5 (C), U3.8
unnamed: C7.1, R71.2, R72.2, R73.2, R74.2, R75.2, U4.13 (-)
unnamed: C7.2, R85.1, R96.2, SW8.5 (C), U4.14
unnamed: C8.1, R81.2, R82.2, R83.2, R84.2, R85.2, U4.9 (-)
unnamed: C8.2, JP6.1 (A), U4.8
unnamed: C9.2, D1.2 (A), Q1.3 (B), R9.2
unnamed: C10.1, D2.1 (K), Q2.3 (B), R10.1
unnamed: C15.1, R18.1, R30.2, U1.6 (-)
unnamed: C15.2, JP3.2 (B), U1.7
unnamed: C16.1, R2.1, R3.1, R5.1, R7.1, U1.2 (-)
unnamed: C17.1, R38.1, R50.2, U3.6 (-)
unnamed: C17.2, JP5.2 (B), U3.7
unnamed: C18.1, R92.1, R93.1, R95.1, R97.1, U3.2 (-)
unnamed: C18.2, JP9.1 (A), R92.2, U3.1
unnamed: J1.1, Q2.2 (C), R10.2
unnamed: J3.1, Q1.2 (C), R9.1
unnamed: J4.1, R16.1
unnamed: J6.1, R26.1
unnamed: J7.1, R36.1
unnamed: J9.1, R46.1
unnamed: J10.1, P1.2, R20.2
unnamed: J12.1, P2.2, R60.2
unnamed: J14.1, P3.2, R40.2
unnamed: J16.1, P4.2, R70.2
unnamed: JP1.1 (A), JP1.2 (C), R58.2, U2.5 (+)
unnamed: JP1.3 (B), R68.2, U4.5 (+)
unnamed: JP2.2 (C), R91.1
unnamed: JP2.3 (B), JP5.1 (A), R38.2
unnamed: JP3.1 (A), R1.1, R18.2
unnamed: JP7.2 (B), U1.11 (V-), U2.11 (V-), U3.11 (V-), U4.11 (V-)
unnamed: JP8.2 (B), U1.4 (V+), U2.4 (V+), U3.4 (V+), U4.4 (V+)
unnamed: P1.3, R19.2
unnamed: P2.3, R59.2
unnamed: P3.3, R39.2
unnamed: P4.3, R69.2
unnamed: R1.2, R4.1, R6.1, U1.3 (+)
unnamed: R5.2, R8.1
unnamed: R11.1, SW1.1
unnamed: R12.1, SW1.2
unnamed: R13.1, SW1.3 (4)
unnamed: R14.1, SW1.4 (8)
unnamed: R21.1, SW2.1
unnamed: R22.1, SW2.2
unnamed: R23.1, SW2.3 (4)
unnamed: R24.1, SW2.4 (8)
unnamed: R31.1, SW3.1
unnamed: R32.1, SW3.2
unnamed: R33.1, SW3.3 (4)
unnamed: R34.1, SW3.4 (8)
unnamed: R41.1, SW4.1
unnamed: R42.1, SW4.2
unnamed: R43.1, SW4.3 (4)
unnamed: R44.1, SW4.4 (8)
unnamed: R51.1, SW5.1
unnamed: R52.1, SW5.2
unnamed: R53.1, SW5.3 (4)
unnamed: R54.1, SW5.4 (8)
unnamed: R61.1, SW6.1
unnamed: R62.1, SW6.2
unnamed: R63.1, SW6.3 (4)
unnamed: R64.1, SW6.4 (8)
unnamed: R71.1, SW7.1
unnamed: R72.1, SW7.2
unnamed: R73.1, SW7.3 (4)
unnamed: R74.1, SW7.4 (8)
unnamed: R81.1, SW8.1
unnamed: R82.1, SW8.2
unnamed: R83.1, SW8.3 (4)
unnamed: R84.1, SW8.4 (8)
unnamed: R95.2, R98.1
unnamed: R91.2, R94.1, R96.1, U3.3 (+)
unnamed: R16.2, R17.2, U1.5 (+)
unnamed: R28.1, R29.2, U2.2 (-)
unnamed: R26.2, R27.2, U2.3 (+)
unnamed: R59.1, U2.6 (-), U2.7
unnamed: R36.2, R37.2, U3.5 (+)
unnamed: R48.2, R50.1, U4.1
unnamed: R48.1, R49.2, U4.2 (-)
unnamed: R46.2, R47.2, U4.3 (+)
unnamed: R69.1, U4.6 (-), U4.7

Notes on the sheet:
Lowpass 2 output
Highpass 2 output
Lowpass 1 output
Resistor Relationships* for 4th-order State Variable Filter Topology (Linkwitz-Riley 24dB/Oct.) R1 = R2 = R7 = "R" (chosen here: 6,8k) R3 = 1,52*R (here: ~10k) R5 (here: Sum of R5+R8) = 0,25*R (here: ~1,7k) R4 = R6 = 0,354*R (here: ~2,4k) -------- Resistor values set with the BCD switches: SW1 = SW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
Highpass 1 output

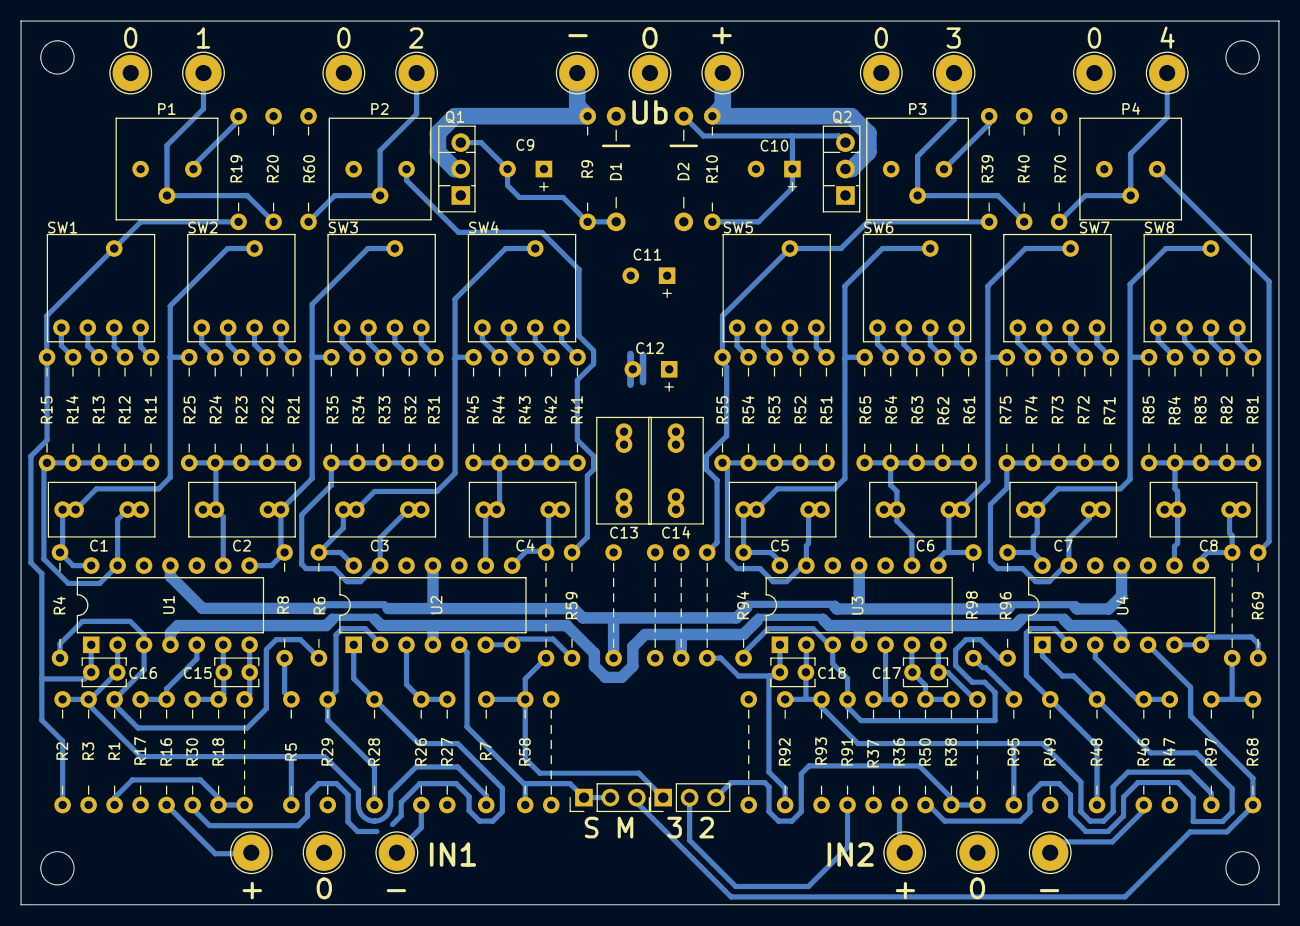
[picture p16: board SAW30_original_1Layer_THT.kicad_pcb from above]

Board: 2 copper layers, 121.0 x 85.0 mm, 151 parts (0 on the bottom side), 99 nets.

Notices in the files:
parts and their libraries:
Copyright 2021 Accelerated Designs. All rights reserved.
